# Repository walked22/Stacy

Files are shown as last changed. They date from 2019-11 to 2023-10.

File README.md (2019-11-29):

# Stacy

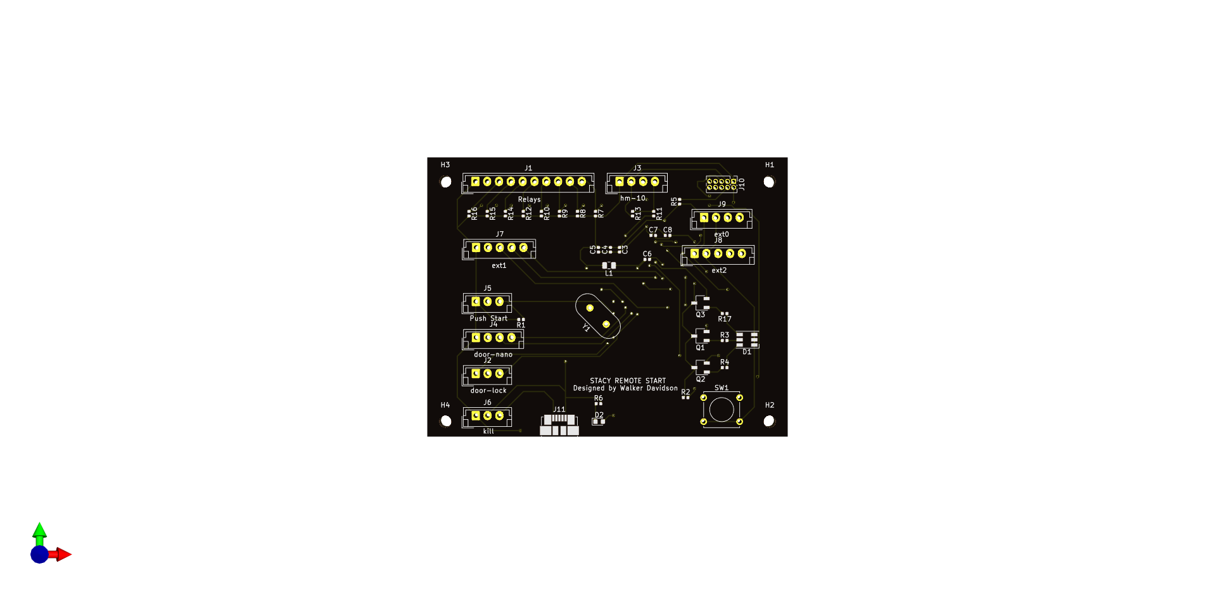
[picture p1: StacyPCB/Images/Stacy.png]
Top View

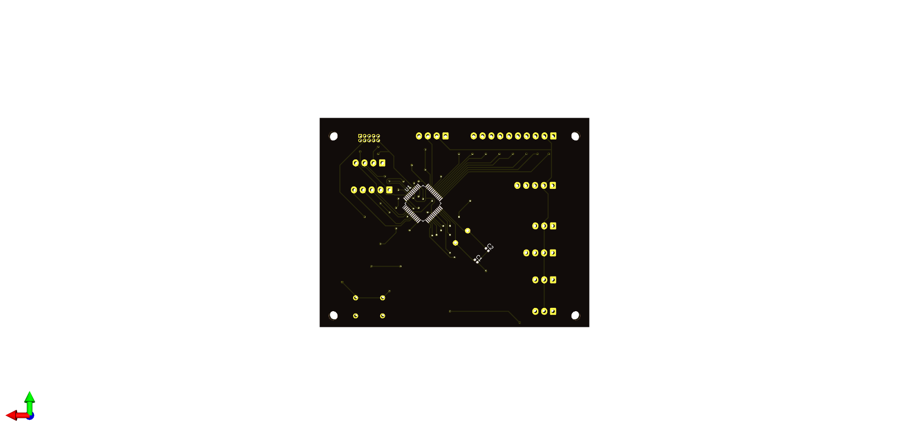
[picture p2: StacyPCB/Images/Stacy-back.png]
Bottom View


Control PCB for Modified 1995 Geo Tracker 

STACY is a is a custom built printed circuit board that remotely starts, warms up, locks, unlocks and 
tracks a 1995 Geo Tracker. The board was designed with expandability in mind allowing for future upgrades.

Features
- ARM Cortex M0+ microcontroller
- Easy locking connectors to withstand vibrations from offroad driving
- Extra connectors with both analog and digital I/O
- Can recieve commands from RFID and BLE
- Battery monitoring 
- Status RGB LED

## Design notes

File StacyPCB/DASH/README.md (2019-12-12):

# Stacy

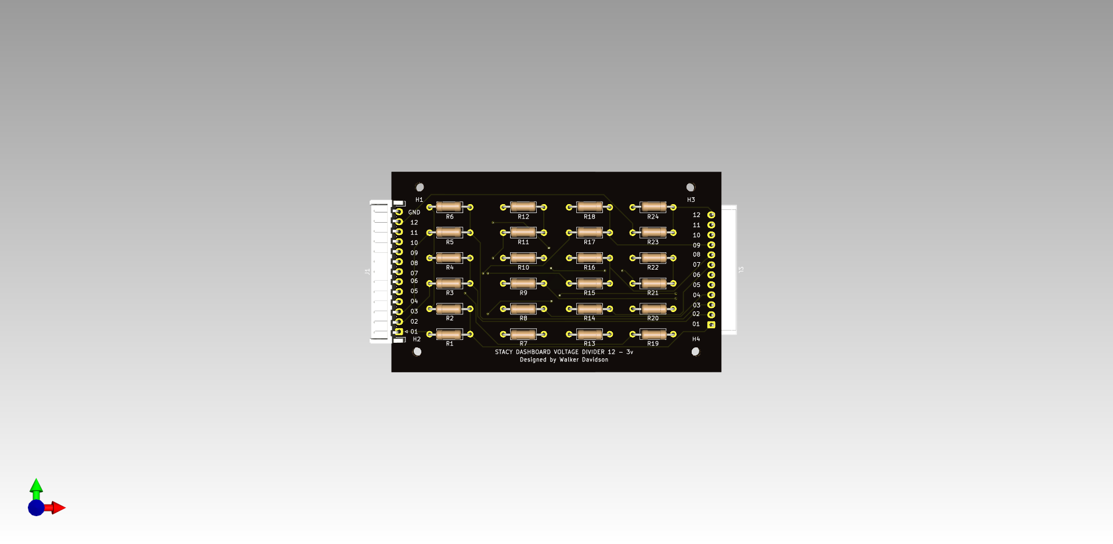
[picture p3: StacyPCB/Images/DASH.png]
Top View

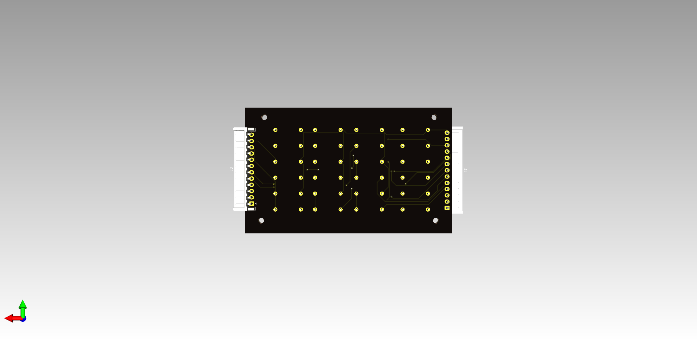
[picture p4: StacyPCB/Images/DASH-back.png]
Bottom View


Voltage Divider PCB for Modified 1995 Geo Tracker Dash Board 

Built to take 12V input and divide down to 3.3V ideal for Raspberry Pi GPIO signals
Features
- 11 12V inputs with ground via locking JST connector
- 11 3.3V outputs with locking JST connector

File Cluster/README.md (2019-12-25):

# Instrument Cluster

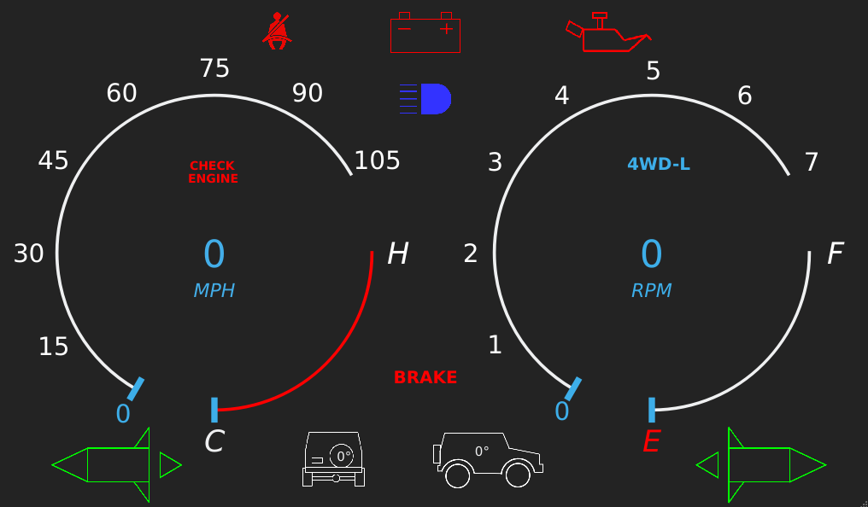
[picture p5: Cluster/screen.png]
View


This is to repace a broken analog gauge instrument cluster for a 1995 Geo Tracker.

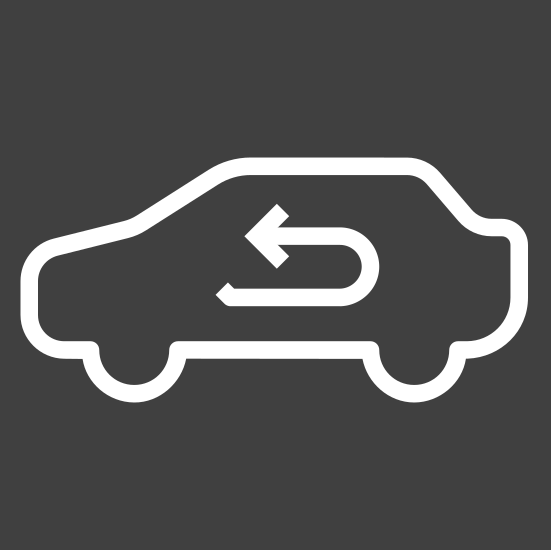
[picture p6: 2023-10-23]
climate2/insideAir.png

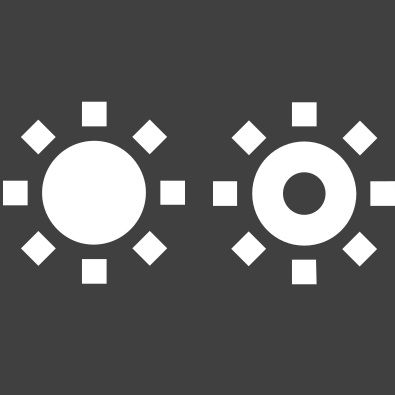
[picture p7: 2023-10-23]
climate2/headlights.png

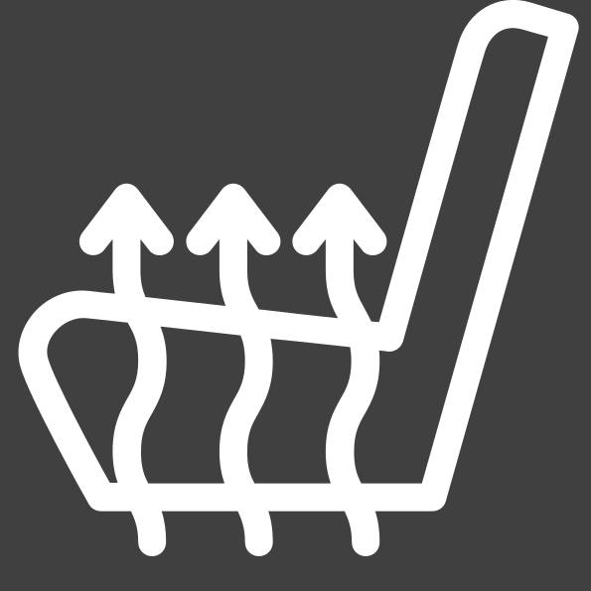
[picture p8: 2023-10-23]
climate2/heatSetaer.png

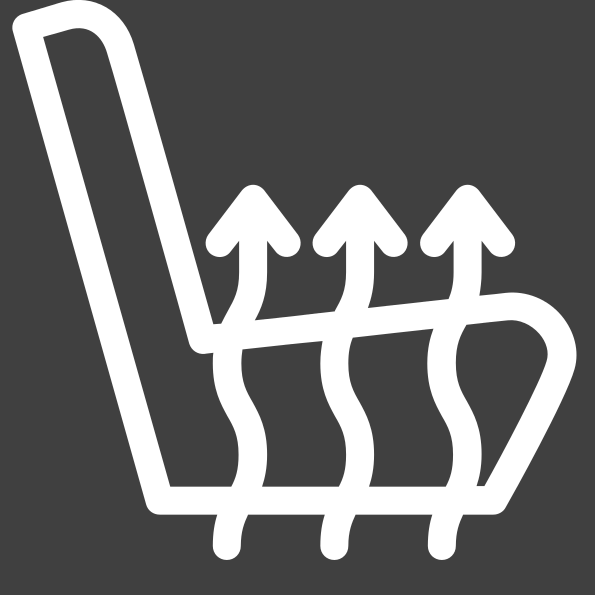
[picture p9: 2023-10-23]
climate2/otherSeat.png

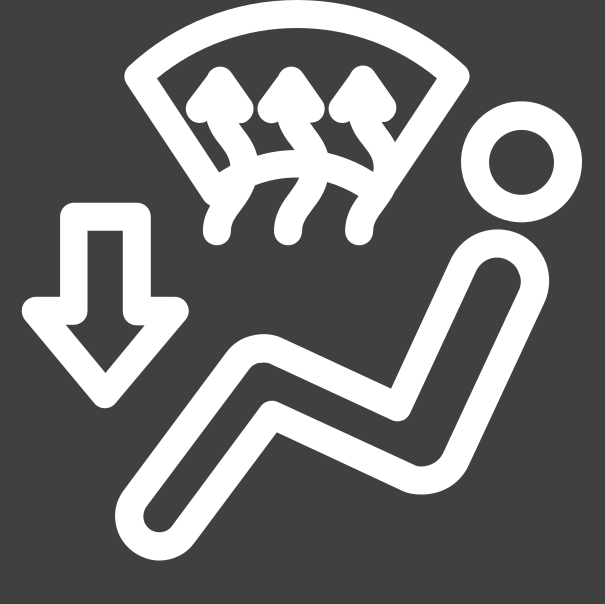
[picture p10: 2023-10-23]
climate2/defrostFeet.png

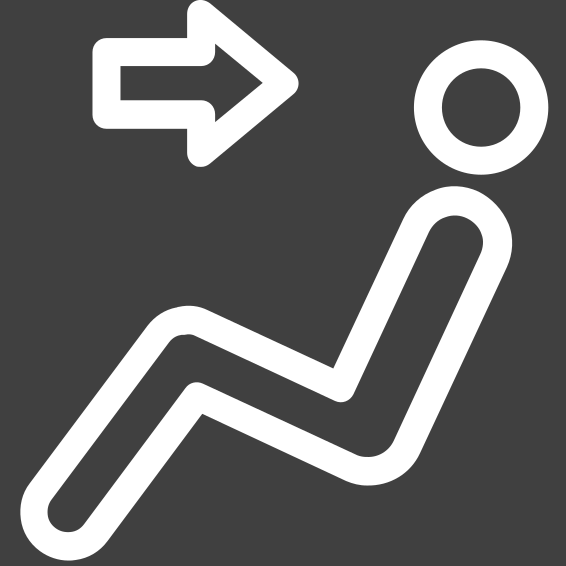
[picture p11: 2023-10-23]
climate2/head.png

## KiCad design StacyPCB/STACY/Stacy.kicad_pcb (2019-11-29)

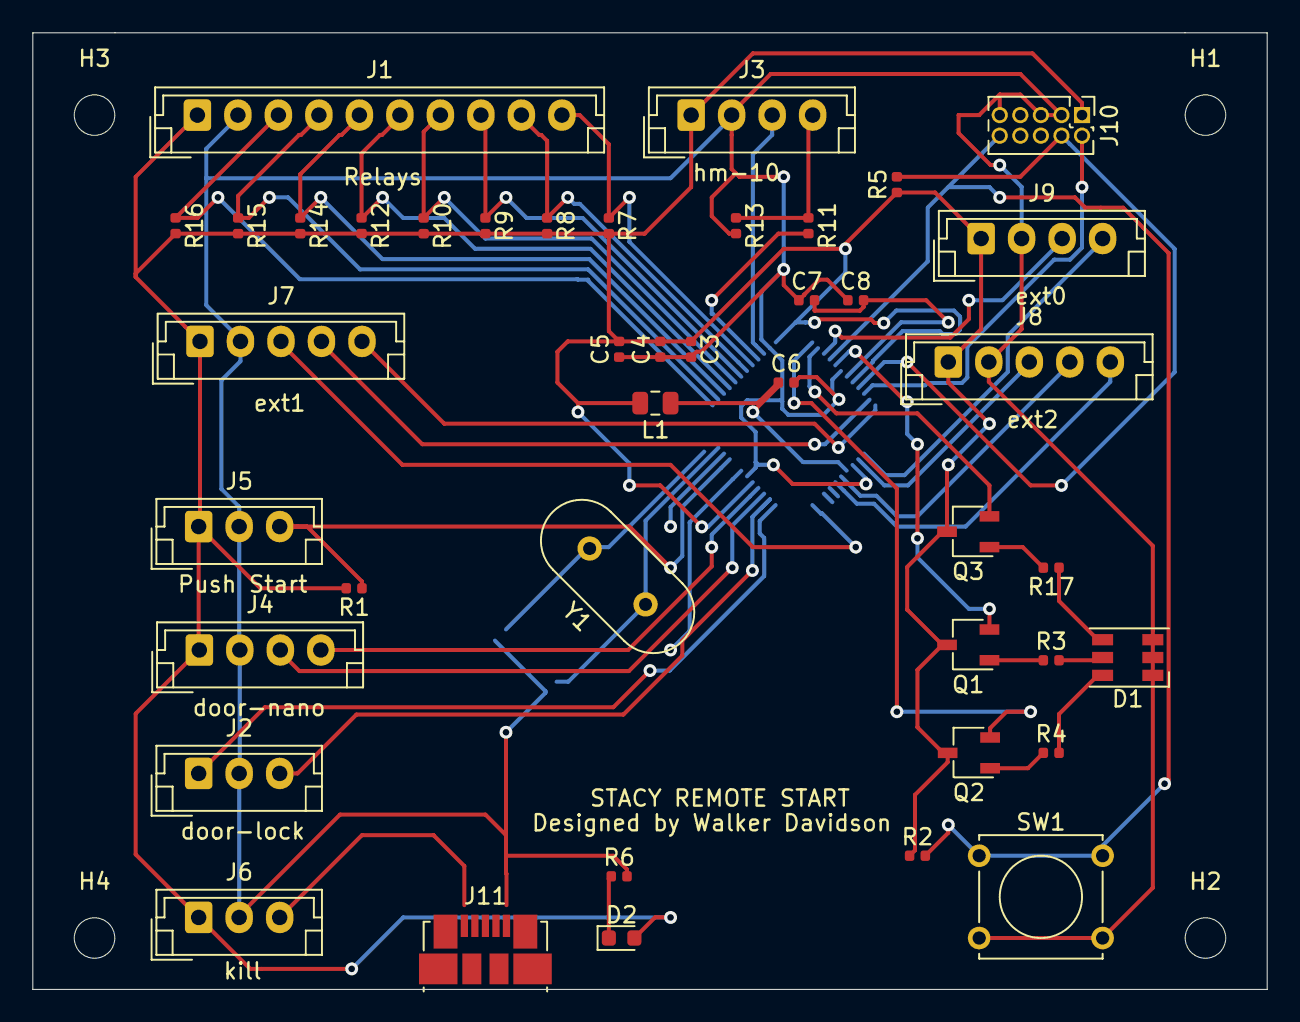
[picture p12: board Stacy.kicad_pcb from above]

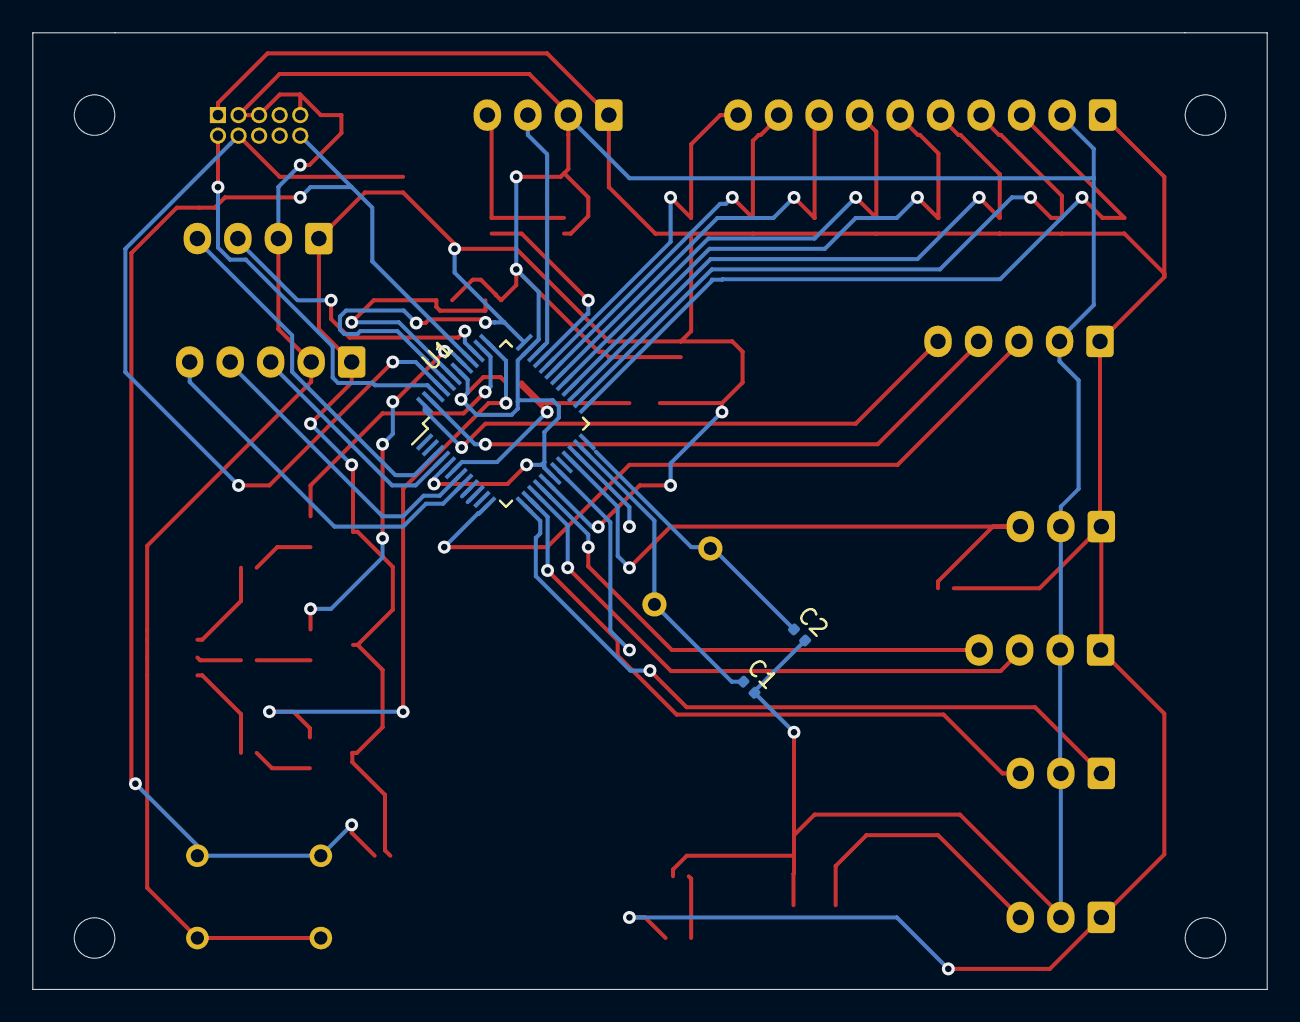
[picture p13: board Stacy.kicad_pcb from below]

Board: 2 copper layers, 76.2 x 59.1 mm, 49 parts (3 on the bottom side), 44 nets.

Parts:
C1, C2: 20pF; C_0402_1005Metric
C3, C5, C8: 100n; C_0402_1005Metric
C4, C6: 10u; C_0402_1005Metric
C7: 1u; C_0402_1005Metric
D1: LED_RGB; LED_RGB_PLCC-6
D2: LED; LED_0603_1608Metric
H1, H2, H3, H4: MountingHole; MountingHole_2.5mm
J1: relays; JST_EH_B10B-EH-A_1x10_P2.50mm_Vertical
J2: door_lock; JST_EH_B3B-EH-A_1x03_P2.50mm_Vertical
J3: ble_hm-10; JST_EH_B4B-EH-A_1x04_P2.50mm_Vertical
J4: door_nano; JST_EH_B4B-EH-A_1x04_P2.50mm_Vertical
J5: push_start; JST_EH_B3B-EH-A_1x03_P2.50mm_Vertical
J6: kill; JST_EH_B3B-EH-A_1x03_P2.50mm_Vertical
J7: ext1; JST_EH_B5B-EH-A_1x05_P2.50mm_Vertical
J8: ext2; JST_EH_B5B-EH-A_1x05_P2.50mm_Vertical
J9: ext0; JST_EH_B4B-EH-A_1x04_P2.50mm_Vertical
J10: SWD Debug; PinHeader_2x05_P1.27mm_Vertical
J11: USB_B_Micro; USB_Micro-B_Molex_47346-0001
L1: MH2029-300Y; L_0805_2012Metric
Q1, Q2, Q3: 2N2219; TSOT-23
R1, R2, R7, R8, R9, R10, R12, R14, R15, R16: 10k; R_0402_1005Metric
R3, R4, R6, R17: 220; R_0402_1005Metric
R5, R11: 1k; R_0402_1005Metric
R13: 2k; R_0402_1005Metric
SW1: SW_Push; SW_Tactile_Straight_KSA0Axx1LFTR
U1: ATSAMD21G18A-AUT; TQFP-48_7x7mm_P0.5mm
Y1: 16MHz; Crystal_HC49-U_Vertical

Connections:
+5V: C3.1, C4.2, C5.2, D2.2, J1.1, J3.1, J4.1, J5.1, J6.1, J7.1, J8.1, J9.1, J10.1, L1.2, Q1.3, Q2.3, Q3.3, R1.2, R2.1, R5.1, R7.2, R8.2, R9.2, R10.2, R12.2, R14.2, R15.2, R16.2, U1.17, U1.36, U1.44
A00: J9.4, U1.3
A01: J8.3, U1.4
A02: J8.4, U1.7
A03: J8.5, U1.8
A07: J7.3, U1.12
A08: J7.4, U1.47
A09: J7.5, U1.48
BLE_RX: J3.3, U1.34
BLE_TX: R11.2, U1.33
GND: C1.2, C2.2, C3.2, C4.1, C5.1, C6.2, C7.1, C8.1, D1.1, D1.2, D1.3, J1.2, J2.2, J3.2, J4.2, J5.2, J6.2, J7.2, J8.2, J9.2, J10.3, J10.5, J10.9, J11.5, R6.2, R13.2, SW1.2, U1.5, U1.18, U1.35, U1.42
IO_DOOR1: J4.3, U1.15
IO_DOOR2: J4.4, U1.16
IO_E0: J9.3, U1.39
IO_E1: Q1.2, U1.41
IO_E2: Q2.2, U1.37
IO_E3: Q3.2, U1.38
IO_LOCK: J2.1, U1.13
IO_R0: J1.3, R16.1, U1.25
IO_R1: J1.4, R15.1, U1.26
IO_R2: J1.5, R14.1, U1.27
IO_R3: J1.6, R12.1, U1.28
IO_R4: J1.7, R10.1, U1.29
IO_R5: J1.8, R9.1, U1.30
IO_R6: J1.9, R8.1, U1.31
IO_R7: J1.10, R7.1, U1.32
IO_START: J5.3, R1.1, U1.21
IO_UNLOCK: J2.3, U1.14
MCU_RST: J10.10, R2.2, SW1.1, U1.40
unnamed: C1.1, U1.23, Y1.1
unnamed: C2.1, U1.24, Y1.2
unnamed: C6.1, L1.1, U1.6
unnamed: C7.2, C8.2, U1.43
unnamed: D1.4, R17.1
unnamed: D1.5, R3.2
unnamed: D1.6, R4.2
unnamed: D2.1, R6.1
unnamed: J3.4, R11.1, R13.1
unnamed: Q1.1, R3.1
unnamed: Q2.1, R4.1
unnamed: Q3.1, R17.2
SWD_CLK: J10.4, R5.2, U1.45
SWD_IO: J10.2, U1.46
kill_sw: J6.3, J11.1

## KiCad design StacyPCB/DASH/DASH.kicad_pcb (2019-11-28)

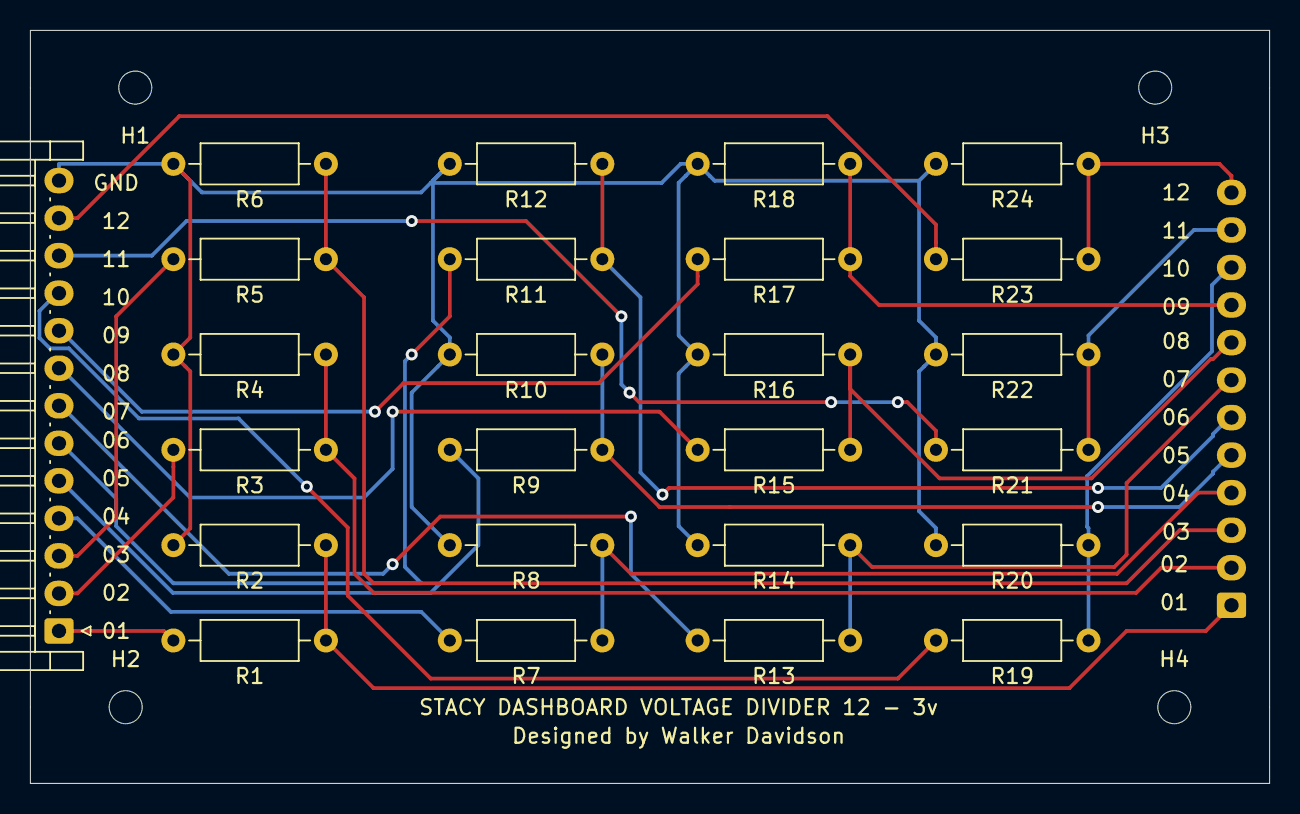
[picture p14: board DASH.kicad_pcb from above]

Board: 2 copper layers, 82.6 x 50.2 mm, 30 parts (1 on the bottom side), 25 nets.

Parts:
H1, H2, H3, H4: MountingHole; MountingHole_2.2mm_M2
J1: Conn_01x13_Female; JST_EH_S13B-EH_1x13_P2.50mm_Horizontal
J2: Conn_01x12_Female; JST_EH_S12B-EH_1x12_P2.50mm_Horizontal
R1, R3, R5, R7, R9, R11, R13, R15, R17, R19, R21, R23: 10k; R_Axial_DIN0207_L6.3mm_D2.5mm_P10.16mm_Horizontal
R2, R4, R6, R8, R10, R12, R14, R16, R18, R20, R22, R24: 3.3k; R_Axial_DIN0207_L6.3mm_D2.5mm_P10.16mm_Horizontal

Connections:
GND: J1.13, R2.2, R4.2, R6.2, R8.2, R10.2, R12.2, R14.2, R16.2, R18.2, R20.2, R22.2, R24.2
unnamed: J1.1, R1.2
unnamed: J1.2, R3.2
unnamed: J1.3, R5.2
unnamed: J1.4, R7.2
unnamed: J1.5, R9.2
unnamed: J1.6, R11.2
unnamed: J1.7, R13.2
unnamed: J1.8, R15.2
unnamed: J1.9, R17.2
unnamed: J1.10, R19.2
unnamed: J1.11, R21.2
unnamed: J1.12, R23.2
unnamed: J2.1, R1.1, R2.1
unnamed: J2.2, R3.1, R4.1
unnamed: J2.3, R5.1, R6.1
unnamed: J2.4, R7.1, R8.1
unnamed: J2.5, R9.1, R10.1
unnamed: J2.6, R11.1, R12.1
unnamed: J2.7, R13.1, R14.1
unnamed: J2.8, R15.1, R16.1
unnamed: J2.9, R17.1, R18.1
unnamed: J2.10, R19.1, R20.1
unnamed: J2.11, R21.1, R22.1
unnamed: J2.12, R23.1, R24.1

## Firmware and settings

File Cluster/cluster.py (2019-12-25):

from PyQt5 import QtCore, QtWidgets, QtGui, Qt, uic
import sys
import time
from os import path
from PyQt5.QtGui import *
from PyQt5.QtCore import *
from PyQt5.QtWidgets import *
from PyQt5.uic import loadUiType
from PyQt5.QtCore import QThread, pyqtSignal
from PyQt5.QtGui import QColor
import serial
import math

qtCreatorFile = "speed.ui"
Ui_MainWindow, QtBaseClass = uic.loadUiType(qtCreatorFile)

r = -120
r1 = -150
z = 100/3
speed = 0
rpm = 0
temp =0
fuel = 0
angle1 = 0
angle2 = 0
z1 = .5
ztemp = .75
zfuel = .9

seatbelt = 0
batt = 0
engine = 0
highs = 0
lights = 0
oil = 0
fourWheel = 0
fourLow = 0
brake = 0
left = 0
right = 0

class mainthread(QThread):
	speedSignal = pyqtSignal('PyQt_PyObject')
	rpmSignal = pyqtSignal('PyQt_PyObject')
	angle1Signal = pyqtSignal('PyQt_PyObject')
	angle2Signal = pyqtSignal('PyQt_PyObject')
	tempSignal = pyqtSignal('PyQt_PyObject')
	fuelSignal = pyqtSignal('PyQt_PyObject')
	warningSignal = pyqtSignal('PyQt_PyObject')

	def __init__(self):                                            # PyQT initialization function
		QThread.__init__(self)

	def __del__(self):
		self.wait()

	def run(self):
		while True:
			with open('data.txt', 'r') as file:
				data = file.read().split(',')
				try:
					self.speedSignal.emit(data[0])
					self.rpmSignal.emit(data[1])
					self.tempSignal.emit(data[2])
					self.angle1Signal.emit(data[3])
					self.angle2Signal.emit(data[4])
					self.fuelSignal.emit(data[5])

					self.warningSignal.emit(data[6:])
				except:
					pass

class MainApp(QtWidgets.QMainWindow, Ui_MainWindow):
	def __init__(self, parent=None):
		super(MainApp, self).__init__(parent)
		QMainWindow.__init__(self)
		self.setupUi(self)
		self.mythread1 = mainthread()
		self.mythread1.start()
		self.setStyle(QStyleFactory.create('breeze'))
		self.setStyleSheet("QMainWindow {background: rgb(35,35,35);}")
		self._margins = 10
		self.speeds = {0: "0", 30: "15", 60: "30", 90: "45", 120: "60", 150: "75", 180: "90", 210: "105", 240: "120"}
		self.rpms = {0: '0', 30: '1', 60: '2', 90: '3', 120: '4', 150: '5', 180: '6', 210: '7'}
		self.mythread1.speedSignal.connect(self.updateSpeed)
		self.mythread1.rpmSignal.connect(self.updateRPM)
		self.mythread1.tempSignal.connect(self.updateTemp)
		self.mythread1.angle1Signal.connect(self.updateAngle1)
		self.mythread1.angle2Signal.connect(self.updateAngle2)
		self.mythread1.fuelSignal.connect(self.updateFuel)
		self.mythread1.warningSignal.connect(self.updateWarning)

	def updateSpeed(self, s):
		global speed
		try:
			speed = int(s)
			#print(speed)
			self.update()
		except:
			pass

	def updateRPM(self, r):
		global rpm
		try:
			rpm = int(r)
		except:
			pass

	def updateAngle1(self, a1):
		global angle1
		try:
			angle1 = int(a1)
		except:
			pass

	def updateAngle2(self, a2):
		global angle2
		try:
			angle2 = int(a2)
		except:
			pass

	def updateTemp(self, T):
		global temp
		try:
			temp = int(T)
		except:
			pass

	def updateFuel(self, F):
		global fuel
		try:
			fuel = int(F)
		except:
			pass

	def updateWarning(self, W):
		global seatbelt
		global batt
		global engine
		global highs
		global oil
		global fourWheel
		global fourLow
		global brake
		global left
		global right
		try:
			seatbelt = int(W[0])
			batt = int(W[1])
			engine = int(W[2])
			highs = int(W[3])
			oil = int(W[4])
			fourWheel = int(W[5])
			fourLow = int(W[6])
			brake = int(W[7])
			left = int(W[8])
			right = int(W[9])
		except:
			pass

	def paintEvent(self, event):
		painter = QPainter()
		painter.begin(self)
		painter.setRenderHint(QPainter.Antialiasing)

		painter.fillRect(event.rect(), self.palette().brush(QPalette.Window))

		#self.drawSpeedLines(painter)
		self.drawSpeed(painter)
		#self.drawSpeedNumbers(painter)
		self.drawSpeedLinesSimple(painter)
		self.drawSpeedNumbersSimple(painter)
		#self.drawSpeedNeedle(painter)
		self.drawSpeedNeedleSimple(painter)

		self.drawRPMLines(painter)
		self.drawRPMNeedle(painter)
		self.drawRPM(painter)
		self.drawRPMNumbers(painter)

		self.drawCar(painter)
		self.drawCarBack(painter)

		self.drawTempLines(painter)
		self.drawTempMarks(painter)
		self.drawTempNeedle(painter)

		self.drawFuelLines(painter)
		self.drawFuelMarks(painter)
		self.drawFuelNeedle(painter)

		self.drawWarnings(painter)

		painter.end()

################################------Speed------##########################################

	def drawSpeedNumbers(self, painter):
		global speed
		x = -210
		i = 0 
		while i < 9:
			painter.save()
			painter.translate(self.width()/4, self.height()/2)
			scale = min((self.width() - self._margins)/120.0, (self.height() - self._margins)/120.0)
			painter.scale(scale*.75, scale*.75)
			font = QFont(self.font())
			font.setPixelSize(8)
			metrics = QFontMetricsF(font)
			painter.setFont(font)
			if speed*2-6 <= i*30 and speed*2+6 >= i*30:
				painter.setPen(QColor(61, 174, 233))
			else:
				painter.setPen(QColor(255, 255, 255))
			painter.translate(math.cos(i*30*math.pi/180+x*math.pi/180)*60, math.sin(i*30*math.pi/180+x*math.pi/180)*60)
			painter.drawText(-metrics.width(self.speeds[30*i])/2, 3, self.speeds[30*i])
			painter.restore()
			i += 1

	def drawSpeedLines(self, painter):
		global speed
		global r
		painter.save()
		painter.translate(self.width()/4, self.height()/2)
		scale = min((self.width() - self._margins)/120.0, (self.height() - self._margins)/120.0)
		painter.scale(scale*.75, scale*.75)
		painter.rotate(r)
		i = 0
		while i < 241:
			if i % 30 == 0:
				if speed*2+6 >= i:
					painter.setPen(QColor(61, 174, 233))
				else:
					painter.setPen(QColor(255, 255, 255))
				painter.drawLine(0, -40, 0, -50)
			else:
				if speed >= 85:
					painter.setPen(QColor(255, 0, 0))
				else:
					if speed*2+6 >= i:
						painter.setPen(QColor(67, 174, 233))
					else:
						painter.setPen(QColor(255, 255, 255))
				painter.drawLine(0, -45, 0, -50)
			painter.rotate(7.5)
			i += 7.5
		painter.restore()

	def drawSpeedLinesSimple(self, painter):
		global speed
		global r1
		global z1
		painter.save()
		painter.translate(self.width()/4, self.height()/2)
		scale = min((self.width() - self._margins)/120.0, (self.height() - self._margins)/120.0)
		painter.scale(scale*.75, scale*.75)
		painter.drawArc(-50, -50, 100, 100, 30*16, 210*16-speed/z1*16)
		if speed <= 85:
			painter.setPen(QColor(61, 174, 233))
		else:
			painter.setPen(QColor(255, 0, 0))
		painter.drawArc(-50,-50,100,100, 240*16, -speed/z1*16)
		painter.restore()

	def drawSpeedNumbersSimple(self, painter):
		global speed
		global z1
		x = -240
		i = 0 
		while i < 8:
			painter.save()
			painter.translate(self.width()/4, self.height()/2)
			scale = min((self.width() - self._margins)/120.0, (self.height() - self._margins)/120.0)
			painter.scale(scale*.75, scale*.75)
			font = QFont(self.font())
			font.setPixelSize(8)
			metrics = QFontMetricsF(font)
			painter.setFont(font)
			if speed/z1-6 <= i*30 and speed/z1+6 >= i*30:
				painter.setPen(QColor(61, 174, 233))
			else:
				painter.setPen(QColor(255, 255, 255))
			painter.translate(math.cos(i*30*math.pi/180+x*math.pi/180)*59, math.sin(i*30*math.pi/180+x*math.pi/180)*59)
			painter.drawText(-metrics.width(self.speeds[30*i])/2, 3, self.speeds[30*i])
			painter.restore()
			i += 1

	def drawSpeedNeedleSimple(self, painter):
		global speed
		global z1
		global r1
		painter.save()
		painter.translate(self.width()/4, self.height()/2)
		painter.rotate(speed/z1+r1)
		scale = min((self.width() - self._margins)/120.0,(self.height() - self._margins)/120.0)
		painter.scale(scale*.75, scale*.75)
		painter.setPen(QPen(Qt.NoPen))
		painter.setBrush(QColor(61, 174, 233))
		painter.drawPolygon(QPolygon([QPoint(-1, -54), QPoint(1, -54), QPoint(1, -46), QPoint(-1, -46)]))
		painter.restore()

	def drawSpeed(self, painter):
		painter.save()
		painter.translate(self.width()/4, self.height()/2)
		scale = min((self.width() - self._margins)/120.0,(self.height() - self._margins)/120.0)
		painter.scale(scale*.75, scale*.75)
		font = QFont(self.font())
		font.setPixelSize(12)
		metrics = QFontMetricsF(font)
		painter.setFont(font)
		if speed >= 85:
			painter.setPen(QColor(255, 0, 0))
		else:
			painter.setPen(QColor(67, 174, 233))
		painter.drawText(QRectF(-20,-10,40,20), Qt.AlignCenter, str(speed))
		font.setPixelSize(6)
		font.setItalic(1)
		painter.setFont(font)
		painter.drawText(QRectF(-20,2,40,20), Qt.AlignCenter, 'MPH')
		painter.restore()

	def drawSpeedNeedle(self, painter):
		global r
		global speed
		if isinstance(speed, int):
			painter.save()
			painter.translate(self.width()/4, self.height()/2)
			painter.rotate(speed*2+r)
			scale = min((self.width() - self._margins)/120.0,(self.height() - self._margins)/120.0)
			painter.scale(scale*.75, scale*.75)
			painter.setPen(QPen(Qt.NoPen))
			painter.setBrush(QColor(255, 255, 255))
			painter.drawPolygon(QPolygon([QPoint(-3, 0), QPoint(0, -35), QPoint(3, 0), QPoint(0, 15), QPoint(-3, 0)]))
			painter.setBrush(QColor(61, 174, 233))
			painter.drawPolygon(QPolygon([QPoint(-1.5, -25), QPoint(0, -35), QPoint(1.5, -25), QPoint(-1.5, -25)]))
			painter.restore()


################################------RPM------##########################################

	def drawRPMNumbers(self, painter):
		global rpm
		global z
		x = -240
		i = 0 
		while i < 8:
			painter.save()
			painter.translate(self.width()*.75, self.height()/2)
			scale = min((self.width() - self._margins)/120.0, (self.height() - self._margins)/120.0)
			painter.scale(scale*.75, scale*.75)
			font = QFont(self.font())
			font.setPixelSize(8)
			metrics = QFontMetricsF(font)
			painter.setFont(font)
			if rpm/z-6 <= i*30 and rpm/z+6 >= i*30:
				painter.setPen(QColor(61, 174, 233))
			else:
				painter.setPen(QColor(255, 255, 255))
			painter.translate(math.cos(i*30*math.pi/180+x*math.pi/180)*58, math.sin(i*30*math.pi/180+x*math.pi/180)*58)
			painter.drawText(-metrics.width(self.rpms[30*i])/2, 3, self.rpms[30*i])
			painter.restore()
			i += 1

	def drawRPMLines(self, painter):
		global rpm
		global r1
		global z
		painter.save()
		painter.translate(self.width()*.75, self.height()/2)
		scale = min((self.width() - self._margins)/120.0, (self.height() - self._margins)/120.0)
		painter.scale(scale*.75, scale*.75)
		painter.drawArc(-50, -50, 100, 100, 30*16, 210*16-rpm/z*16)
		if rpm <= 4500:
			painter.setPen(QColor(61, 174, 233))
		else:
			painter.setPen(QColor(255, 0, 0))
		painter.drawArc(-50,-50,100,100, 240*16, -rpm/z*16)
		painter.restore()

	def drawRPMNeedle(self, painter):
		global rpm
		global r1
		global z
		painter.save()
		painter.translate(self.width()*.75, self.height()/2)
		painter.rotate(rpm/z+r1)
		scale = min((self.width() - self._margins)/120.0,(self.height() - self._margins)/120.0)
		painter.scale(scale*.75, scale*.75)
		painter.setPen(QPen(Qt.NoPen))
		painter.setBrush(QColor(61, 174, 233))
		painter.drawPolygon(QPolygon([QPoint(-1, -54), QPoint(1, -54), QPoint(1, -46), QPoint(-1, -46)]))
		painter.restore()

	def drawRPM(self, painter):
		global rpm
		painter.save()
		painter.translate(self.width()*.75, self.height()/2)
		scale = min((self.width() - self._margins)/120.0,(self.height() - self._margins)/120.0)
		painter.scale(scale*.75, scale*.75)
		font = QFont(self.font())
		font.setPixelSize(12)
		metrics = QFontMetricsF(font)
		painter.setFont(font)
		if rpm <= 4500:
			painter.setPen(QColor(61, 174, 233))
		else:
			painter.setPen(QColor(255, 0, 0))
		painter.drawText(QRectF(-20,-10,40,20), Qt.AlignCenter, str(rpm))
		font.setPixelSize(6)
		font.setItalic(1)
		painter.setFont(font)
		painter.drawText(QRectF(-20,2,40,20), Qt.AlignCenter, 'RPM')
		painter.restore()

################################------CAR------##########################################

	def drawCar(self, painter):
		global angle1
		painter.save()
		pic = QPixmap("Geo.png")
		font = QFont(self.font())
		font.setPixelSize(30)
		metrics = QFontMetricsF(font)
		painter.setFont(font)
		painter.translate(self.width()*.5, self.height()*.85)
		painter.scale(.5,.5)
		painter.rotate(-angle1)
		painter.drawPixmap(0, 0, pic)
		painter.drawText(QRectF(85,25,60,40), Qt.AlignCenter, str(angle1)+u"\u00b0")
		painter.restore()

	def drawCarBack(self, painter):
		global angle2
		painter.save()
		pic = QPixmap("GeoBack.png")
		font = QFont(self.font())
		font.setPixelSize(50)
		metrics = QFontMetricsF(font)
		painter.setFont(font)
		painter.translate(self.width()*.35, self.height()*.85)
		painter.scale(.3,.3)
		painter.rotate(-angle2)
		painter.drawPixmap(0, 0, pic)
		painter.drawText(QRectF(135,75,60,40), Qt.AlignCenter, str(angle2)+u"\u00b0")
		painter.restore()

################################------Temp------##########################################

	def drawTempLines(self, painter):
		global temp
		global r1
		global ztemp
		painter.save()
		painter.translate(self.width()/4, self.height()/2)
		scale = min((self.width() - self._margins)/120.0, (self.height() - self._margins)/120.0)
		painter.scale(scale*.75, scale*.75)
		painter.setPen(QColor(255, 0, 0))
		painter.drawArc(-50, -50, 100, 100, -0*16, -90*16+temp*ztemp*16)
		if temp <= 100:
			painter.setPen(QColor(61, 174, 233))
		else:
			painter.setPen(QColor(255, 0, 0))
		painter.drawArc(-50,-50,100,100, -90*16, 0+temp*ztemp*16)
		painter.restore()

	def drawTempMarks(self, painter):
		global temp
		painter.save()
		painter.translate(self.width()/4, self.height()/2+230)
		font = QFont(self.font())
		font.setPixelSize(35)
		metrics = QFontMetricsF(font)
		font.setItalic(1)
		painter.setFont(font)
		painter.drawText(-metrics.width('C')/2, 3, 'C')
		painter.translate(215,-220)
		if temp >= 100:
			painter.setPen(QColor(255, 0, 0))
		else:
			painter.setPen(QColor(255, 255, 255))
		painter.drawText(-metrics.width('H')/2, 3, 'H')
		painter.restore()

	def drawTempNeedle(self, painter):
		global temp
		global ztemp
		painter.save()
		painter.translate(self.width()/4, self.height()/2)
		painter.rotate(-temp*ztemp+180)
		scale = min((self.width() - self._margins)/120.0,(self.height() - self._margins)/120.0)
		painter.scale(scale*.75, scale*.75)
		painter.setPen(QPen(Qt.NoPen))
		painter.setBrush(QColor(61, 174, 233))
		painter.drawPolygon(QPolygon([QPoint(-1, -54), QPoint(1, -54), QPoint(1, -46), QPoint(-1, -46)]))
		painter.restore()

################################------Fuel------##########################################

	def drawFuelLines(self, painter):
		global fuel
		global r1
		global zfuel
		painter.save()
		painter.translate(self.width()*.75, self.height()/2)
		scale = min((self.width() - self._margins)/120.0, (self.height() - self._margins)/120.0)
		painter.scale(scale*.75, scale*.75)
		painter.drawArc(-50, -50, 100, 100, -0*16, -90*16+fuel*zfuel*16)
		if fuel <= 20:
			painter.setPen(QColor(255, 0, 0))
		elif 20 < fuel <= 80:
			painter.setPen(QColor(61, 174, 233))
		else:
			painter.setPen(QColor(0, 255, 0))
		painter.drawArc(-50,-50,100,100, -90*16, 0+fuel*zfuel*16)
		painter.restore()

	def drawFuelMarks(self, painter):
		global fuel
		painter.save()
		painter.translate(self.width()*.75, self.height()/2+230)
		font = QFont(self.font())
		font.setPixelSize(35)
		metrics = QFontMetricsF(font)
		font.setItalic(1)
		painter.setFont(font)
		if fuel <= 20:
			painter.setPen(QColor(255, 0, 0))
		else:
			painter.setPen(QColor(255, 255, 255))
		painter.drawText(-metrics.width('E')/2, 3, 'E')
		painter.translate(215,-220)
		if 20 < fuel <= 80:
			painter.setPen(QColor(255, 255, 255))
		elif fuel > 80:
			painter.setPen(QColor(0, 255, 0))
		else:
			painter.setPen(QColor(255, 255, 255))
		painter.drawText(-metrics.width('F')/2, 3, 'F')
		painter.restore()

	def drawFuelNeedle(self, painter):
		global fuel
		global zfuel
		painter.save()
		painter.translate(self.width()*.75, self.height()/2)
		painter.rotate(-fuel*zfuel+180)
		scale = min((self.width() - self._margins)/120.0,(self.height() - self._margins)/120.0)
		painter.scale(scale*.75, scale*.75)
		painter.setPen(QPen(Qt.NoPen))
		painter.setBrush(QColor(61, 174, 233))
		painter.drawPolygon(QPolygon([QPoint(-1, -54), QPoint(1, -54), QPoint(1, -46), QPoint(-1, -46)]))
		painter.restore()

################################------Warning Indicators------##########################################
	
	def drawWarnings(self, painter):
		global seatbelt
		global batt
		global engine
		global highs
		global lights
		global oil
		global fourWheel
		global fourLow
		global brake
		global left
		global right
		painter.save()
		sb_pic = QPixmap("seatbelt.png")
		oil_pic = QPixmap("oil.png")
		batt_pic = QPixmap("batt.png")
		highs_pic = QPixmap("highs.png")
		left_pic = QPixmap("left.png")
		right_pic = QPixmap("right.png")
		font = QFont(self.font())
		font.setPixelSize(14)
		metrics = QFontMetricsF(font)
		painter.translate(self.width()*.30, self.height()*.03)
		painter.scale(.15,.15)
		if seatbelt == 1:
			painter.drawPixmap(0, 0, sb_pic)
		#painter.drawText(QRectF(135,75,60,40), Qt.AlignCenter, str(angle2)+u"\u00b0")
		if batt == 1:
			painter.resetTransform()
			painter.translate(self.width()*.5-50, self.height()*.03)
			painter.scale(.08,.08)
			painter.drawPixmap(self.rect(), batt_pic)
		if oil == 1:
			painter.resetTransform()
			painter.translate(self.width()*.7-50, self.height()*.03)
			painter.scale(.1,.08)
			painter.drawPixmap(self.rect(), oil_pic)
		if engine == 1:
			painter.setPen(QColor(255, 0, 0))
			font.setBold(1)
			painter.setFont(font)
			painter.resetTransform()
			painter.translate(self.width()/4-5, self.height()/3)
			painter.drawText(-metrics.width('CHECK')/2, 3, 'CHECK')
			painter.translate(0,15)
			painter.drawText(-metrics.width('ENGINE')/2, 3, 'ENGINE')
		if fourWheel == 1:
			painter.setPen(QColor(61, 174, 233))
			font.setBold(1)
			font.setPixelSize(20)
			painter.setFont(font)
			painter.resetTransform()
			painter.translate(self.width()*.75-13, self.height()/3)
			painter.drawText(-metrics.width('4WD')/2, 3, '4WD')
		if fourLow == 1:
			painter.resetTransform()
			painter.setPen(QColor(61, 174, 233))
			font.setBold(1)
			font.setPixelSize(20)
			painter.setFont(font)
			painter.translate(self.width()*.75+30, self.height()/3)
			painter.drawText(-metrics.width('-L')/2, 3, '-L')
		if brake == 1:
			painter.resetTransform()
			painter.setPen(QColor(255, 0, 0))
			font.setBold(1)
			font.setPixelSize(20)
			painter.setFont(font)
			painter.translate(self.width()/2-metrics.width('BRAKE')/2, self.height()*.75)
			painter.drawText(-metrics.width('BRAKE')/2, 3, 'BRAKE')
		if highs == 1:
			painter.resetTransform()
			painter.translate(self.width()*.5-40, self.height()*.17)
			painter.scale(.06,.06)
			painter.drawPixmap(self.rect(), highs_pic)
		if left == 1:
			painter.resetTransform()
			painter.translate(self.width()*.2-140, self.height()*.84)
			painter.scale(.15, .15)
			painter.drawPixmap(self.rect(), left_pic)
		if right == 1:
			painter.resetTransform()
			painter.translate(self.width()*.8, self.height()*.84)
			painter.scale(.15,.15)
			painter.drawPixmap(self.rect(), right_pic)
		painter.restore()



def main():
	app = QApplication(sys.argv)        # start PyQT
	window = MainApp()
	#window.setWindowFlags(QtCore.Qt.FramelessWindowHint)
	window.show()
	app.exec_()

if __name__ == '__main__':              # run PyQT
	main()

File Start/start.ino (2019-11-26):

#include <AltSoftSerial.h>
AltSoftSerial BTserial; 

String c;
int val;
float current_time;
int starting;
int car_on;

void setup() {
 BTserial.begin(9600);  
 pinMode(0, OUTPUT);
 pinMode(7, OUTPUT);
 pinMode(4, INPUT_PULLUP);
 pinMode(5, OUTPUT);
 pinMode(3, OUTPUT);
 pinMode(6, OUTPUT);
 pinMode(2, OUTPUT);
 pinMode(13, OUTPUT);
 pinMode(10, INPUT_PULLUP);
 pinMode(1, INPUT);
 pinMode(11, OUTPUT);
 pinMode(12, OUTPUT);
 digitalWrite(7, HIGH);
 digitalWrite(5, HIGH);
 digitalWrite(3, HIGH);
 digitalWrite(6, HIGH);
 digitalWrite(2, HIGH);
 digitalWrite(0, LOW);
 digitalWrite(11, HIGH);
 digitalWrite(12, HIGH);
 digitalWrite(13, HIGH);
 starting = 1;
 car_on = 0;

}
void loop() {
 if (BTserial.available()){
        c = BTserial.readString();
        if (c == "passwordHere"){
          unlock();
          carOn();
        }
        if (c == "passwordHere" && car_on == 0){
          btstart();
        }
        if (c == "passwordHere"){
          unlock();
        }
        if (c == "passwordHere"){
          lock();
        }
        if (c == "passwordHere"){
          car_on = 0;
          carOff();
        }
    }
    
  if (digitalRead(10) == LOW && digitalRead(1) == HIGH){
    unlock();
    carOn();
  }
  delay(200);
  val = digitalRead(4);
  if (val == LOW){
    car_on = 0;
    carOff();
  }
}
void carOn() {
   digitalWrite(7, LOW);
   digitalWrite(3, LOW);
   digitalWrite(6, LOW);
   starting = 1;
   current_time = millis()+120000.0;
   while ((current_time - millis()) >= 0 && car_on == 0) {
      val = digitalRead(4);
      while(val == LOW){
         digitalWrite(7, HIGH);
         digitalWrite(3, HIGH);
         digitalWrite(6, HIGH);
         digitalWrite(5, LOW);
         digitalWrite(2, LOW);
         digitalWrite(13, LOW);
         starting = 0;
         val = digitalRead(4);
      }
      if (val == HIGH){
       digitalWrite(5, HIGH);
       digitalWrite(2, HIGH);
       digitalWrite(13, HIGH);
       digitalWrite(3, LOW);
       digitalWrite(7, LOW);
       digitalWrite(6, LOW);
      }
      if (starting == 0){
       current_time = -120000.0;
       car_on = 1;
      }
   }
   delay(200);
 }
 
void btstart(){
  if (car_on == 0){
   car_on = 1;
   digitalWrite(7, LOW);
   digitalWrite(3, LOW);
   digitalWrite(6, LOW);
   digitalWrite(11, LOW);
   digitalWrite(12, HIGH);
   delay(500);
   digitalWrite(11, HIGH);
   digitalWrite(12, HIGH);
   delay(500);
   digitalWrite(7, HIGH);
   digitalWrite(3, HIGH);
   digitalWrite(6, HIGH);
   digitalWrite(5, LOW);
   digitalWrite(2, LOW);
   digitalWrite(13, LOW);
   delay(1000);
   digitalWrite(5, HIGH);
   digitalWrite(2, HIGH);
   digitalWrite(13, HIGH);
   digitalWrite(3, LOW);
   digitalWrite(7, LOW);
   digitalWrite(6, LOW);
   delay(100);
   }
}

void carOff(){
   digitalWrite(5, HIGH);
   digitalWrite(2, HIGH);
   digitalWrite(13, HIGH);
   digitalWrite(3, HIGH);
   digitalWrite(7, HIGH);
   digitalWrite(6, HIGH);
   car_on = 0;
}

void lock(){
  digitalWrite(11, HIGH);
  digitalWrite(12, LOW);
  delay(500);
  digitalWrite(11, HIGH);
  digitalWrite(12, HIGH);
}

void unlock(){
  digitalWrite(11, LOW);
  digitalWrite(12, HIGH);
  delay(500);
  digitalWrite(11, HIGH);
  digitalWrite(12, HIGH);
}

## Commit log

2019-11-26 created git repo for stacy pcb
    [Stacy.kicad_pcb, Stacy.sch]
2019-11-26 Changed color of up and down buttons
2019-11-26 AC button now chenges color when checked
2019-11-27 Fixed AC startup color
    [GUI.py]
2019-11-27 fixed color variable name
    [GUI.py]
2019-11-28 Added git repo for dashboard voltage divider
    [DASH-B_Cu.gbr, DASH-B_Mask.gbr, DASH-B_Paste.gbr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]
2019-11-29 Routed all decoupling caps and fixed clock footprint. This version has been manufactured
    [Stacy.kicad_pcb, Stacy.sch]
2019-11-29 Added images of STACY PCB
2019-12-12 Removed drl and gbr files
    [DASH-B_Cu.gbr, DASH-B_Mask.gbr, DASH-B_Paste.gbr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]
2019-12-12 Added images of voltage divider board
2019-12-20 added internal temperature display
2019-12-20 added self to thread functions
2019-12-20 Added thread starter
2019-12-20 fixed threading(first working)
2019-12-21 added code for second temp sensor
2020-01-28 fixed transistor
    [Stacy.sch, file5E3BCF63.sch]
2023-11-06 test script for accelerometer
2023-11-06 rotating pitch/yaw
2023-11-07 fixed pitch/yaw labels
2024-02-20 added relay controls
2024-03-13 changed to sliders for pitch and roll, added temp sensors
